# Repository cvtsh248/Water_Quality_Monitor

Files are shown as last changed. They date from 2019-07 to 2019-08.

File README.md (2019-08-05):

# Water Quality Monitor

This is an affordable, work-in-progress arduino based system that rates/monitors changes in water quality over a period of time. The system could potentially be used to monitor/rate the changes in tap water over time. When a significant change occurs, the system alerts the user. A change in water quality could indicate some form of contamination. 

The system currently monitors total dissolved solids (TDS) and turbidity using homemade sensors. More information is provided in the [wiki](https://github.com/cvtsh248/Water_Quality_Monitor/wiki). 

# Components Required
More information regarding the construction of the sensors and circuitry is in the [wiki](https://github.com/cvtsh248/Water_Quality_Monitor/wiki).
* Computer with functional USB ports.
* Arduino UNO 
* Resistors (10kΩ, 3.3kΩ, 100Ω, 20kΩ), note that you may need resistors of other values, more information is provided in the [wiki](https://github.com/cvtsh248/Water_Quality_Monitor/wiki)
* Wire
* Red LED (for the turbidity sensor)
* Light Dependent Resistor (for the turbidity sensor)
* Bottle Cap (For turbidity sensor, more infornamtion in the [wiki](https://github.com/cvtsh248/Water_Quality_Monitor/wiki))
* Plugpoint with two functional prongs (for the TDS sensor)

# Software Dependencies
* Processing IDE
  * processing.serial
  * controlP5
  * java.io.BufferedWriter
  * java.io.FileWriter
* Arduino IDE

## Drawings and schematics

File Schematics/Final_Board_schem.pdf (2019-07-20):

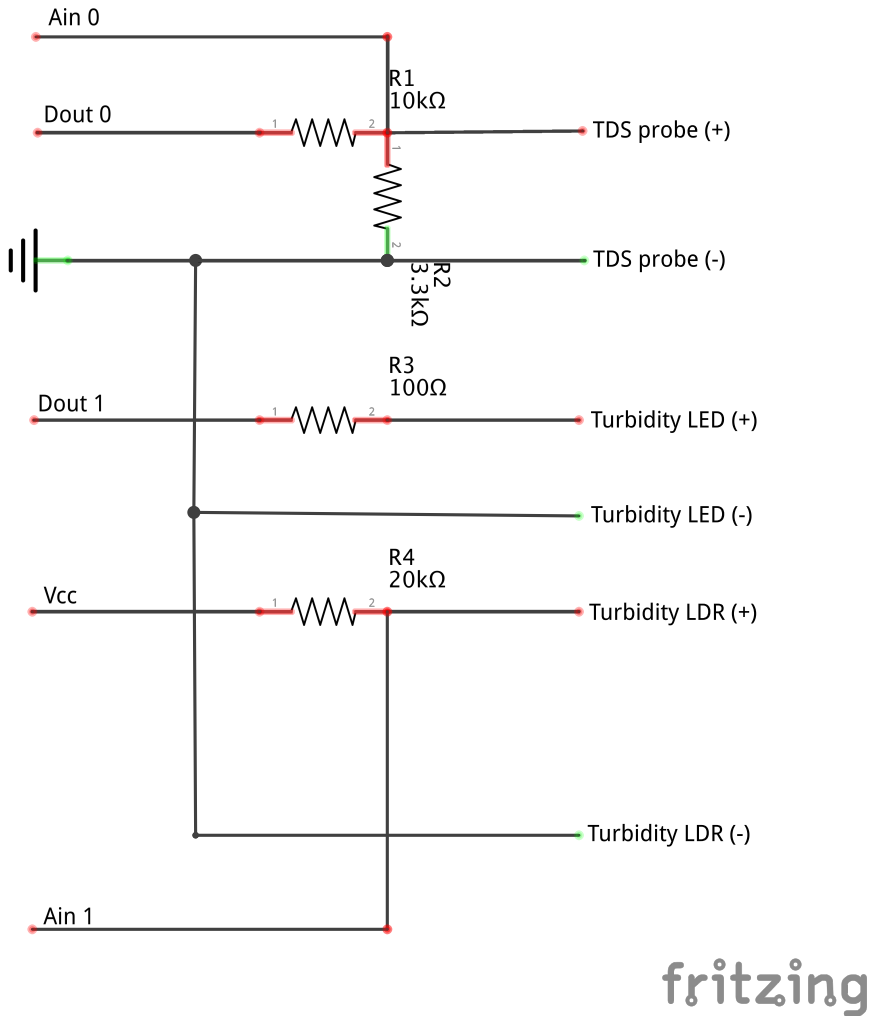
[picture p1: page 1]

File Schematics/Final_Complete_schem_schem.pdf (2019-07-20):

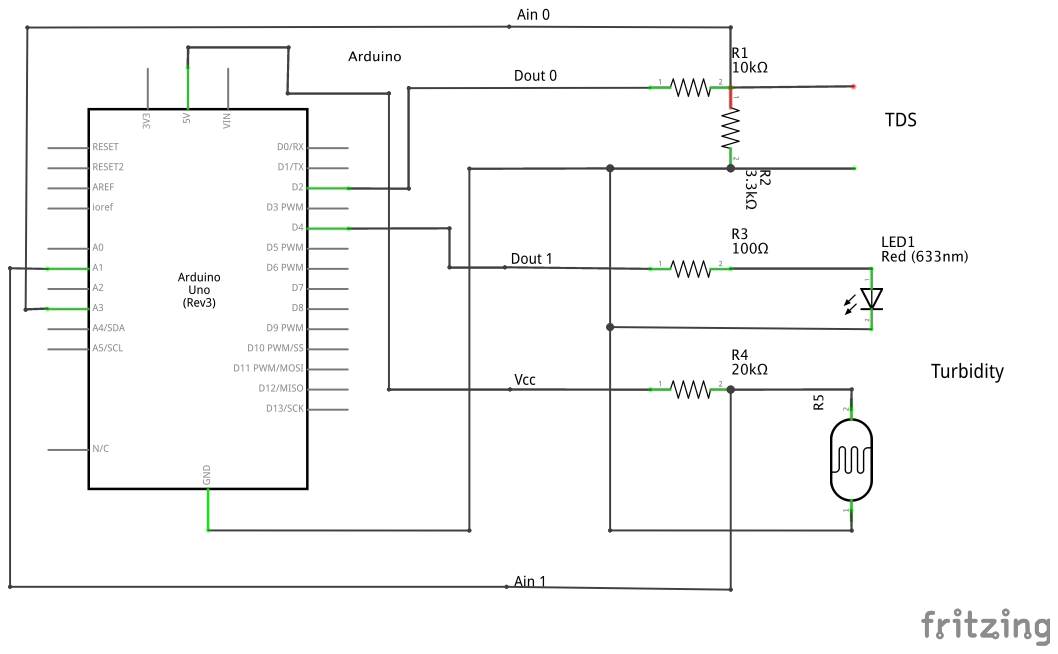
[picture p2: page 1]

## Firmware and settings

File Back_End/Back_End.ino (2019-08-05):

// Backend

/*
 * TO DO:
 * 1. Add in turbidity functionality [DONE]
 * 2. Calibrate sensor [DONE]
 */

void setup() {
  Serial.begin(9600);
  analogReference(INTERNAL);
  pinMode(2, OUTPUT);
  pinMode(4, OUTPUT);

}

//for tds
float volt = 0; 
float avg = 0;
char incoming; //see when to send what

//for turbidity
float val_light = 0;
float val_no_light = 0;
float val = 0;
float avgval = 0;

void loop() {
  avg = 0;
  if (Serial.available()>0){
    
    incoming = Serial.read();
    Serial.println(incoming);
    /*
     *  To prevent electrolysis,
     *  the program does not apply a constant voltage to the water, 
     *  but only when you ask the program to send you a reading.
     */
    if (incoming == 'd'){ //tds
      //reading data
      for (int i = 0; i <= 100; i++){
        digitalWrite(2, HIGH);
        volt = analogRead(A3);
        avg += volt; //an average is taken for the sake of accuracy, and denoising
      }
      digitalWrite(2, LOW);
      avg = avg/100;
      
      
    /*
     * A turbidity sensor measures the cloudiness of water. 
     * This can be achieved using a LDR and a LED. 
     * The less light that comes through from the LED to the LDR, the cloudier the water is. 
     * To cancel out background light, I am turning the LED on and off every 50 milliseconds. 
     * The reading of the LDR during the time that the LED is off 
     * can be subtracted from the reading of the LDR during the 
     * time that the LED is on, to get a final turbidity reading, 
     * free of background light. 
     * In theory this eliminates the need of something 
     * like a dark box for the system to be housed in. 
     */
      //reading data
      for (int n = 0; n <= 20; n++){
        digitalWrite(4, LOW); 
        val_no_light = analogRead(A1); //reading with no light
        delay(10); //1 ms delay
        digitalWrite(4, HIGH);
        val_light = analogRead(A1); //reading with light on
        delay(10); //1 ms delay
        val = val_light-val_no_light; //subtracting the two
        avgval += val;
      }
      digitalWrite(4, LOW); 
      avgval /= 20; //calculating average for the sake of accuracy/denoising
      
      Serial.print(avg); //average printed to serial
      Serial.print(',');
      Serial.println(avgval); //print to serial
      
      avgval = 0;
      avg = 0;
    }
  }
  Serial.flush();
}

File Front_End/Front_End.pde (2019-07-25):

//Front End

/*

This is the front end.
This works in unison with the back end.
Only edit lines that ask you to,
if you don't want to break anything.

*/

import controlP5.*;

import processing.serial.*;

import java.io.BufferedWriter;

import java.io.FileWriter;

Serial arduino;

ControlP5 cp5;

float std(float data[]) { //function to calculate standard deviation
  float avg = 0;
  float stdev = 0;
  float nans = 0; //count how many nan
  for (int i = 0; i < data.length; i++) { //calculating average
    if (Float.isNaN(data[i])==false){
      avg += data[i];
    }
    if (Float.isNaN(data[i])==true){
      nans+=1;
    }
  }
  avg /= (data.length-nans);
  for (int i = 0; i < (data.length-nans); i++) {
    if (Float.isNaN(data[i])==false){
      stdev += sq(data[i]-avg);
    }
    
  }
  stdev /= (data.length-nans); //calculating standard deviation
  stdev = sqrt(stdev);
  return (stdev);
}

boolean sigma(float data[], float val){ //evaluate standard deviation
  float stdev = std(data);
  float avg = 0;
  float nans = 0; //count how many nan
  float diff = 0;
  float sigmas = 0;
  for (int i = 0; i < data.length; i++) { //calculating average
    if (Float.isNaN(data[i])==false){
      avg += data[i];
    }
    if (Float.isNaN(data[i])==true){
      nans+=1;
    }
  }
  avg /= (data.length-nans);
  diff = val-avg;
  
  sigmas = diff/stdev;
  println(sigmas);
  if (abs(sigmas) > 3){
    return (true);
  }else{
    return (false);
  }
}


String buff[] = {""}; //reseting file
float Buff[] = {}; //for reseting lists
float tds[] = {}; //tds values
float turbidity[] = {}; //turbidty values
String val = null; //buffer for tds
String val_t = null; //buffer for turbidity
boolean range = false; //in acceptable range of standard deviation or not (tds)
boolean range_t = false; //same as range but for turbidity 
float s = 0; //variable containing standard deviation for tds
float s_t = 0; //standard deviation for turbidity
String [] lines; //open file for tds
String [] lines_t; //open file for turbidity

void setup() {
  size(400,400);
  
  arduino = new Serial (this, "/dev/ttyACM0", 9600); //initialising arduino serial connection
  arduino.bufferUntil( '\n' );
  
  lines = loadStrings("log_tds.txt"); //load save file for tds
  lines_t = loadStrings("log_turb.txt"); //load save file for turbidity
  
  //gui elements
  cp5 = new ControlP5(this);
  cp5.addButton("Data").setValue(0).setPosition(20,40).setSize(90,40);
  cp5.addButton("Save").setValue(0).setPosition(20,100).setSize(90,40);
  cp5.addButton("Reset").setValue(0).setPosition(20,160).setSize(90,40);
  
  for (int i = 0; i < lines.length; i++){
    tds = append(tds,float(lines[i]));
  }
  
  for (int i = 0; i < lines_t.length; i++){
    turbidity = append(turbidity,float(lines_t[i]));
  }
  
}


void draw() { //begin application
  //tds
  background(0); //refresh background
  text("Value of TDS:",160,45);
  if (tds.length > 0 && val != null){
    text(float(val),250,45); //display tds value, in calibration mode: taking value from tds buffer array
    //text(float(val)*m+c,250,45); <If you have calibration data (linear), uncomment this line and comment out line 119, replace m with gradient and c with constant and remove this text>
    //text(a*pow(float(val),exp)+c,250,45); <If you have calibration data (exponential), uncomment this line and comment out line 119, replace exp with the exponent and c with constant and remove this text>
    //text(a*pow(float(val),2)+b*(float(val))+c,250,45); <If you have calibration data (quadratic), uncomment this line and comment out line 119, replace a with the coefficient of x^2, b with the coefficient of x and c with constant and remove this text>
    
  }
  if (val != null){
    s = std(tds); //calculate standard deviation of the tds array
  }
  text("Standard Deviation:",160,70); //lines 82&83 are responsible for displaying standard deviation
  text(String.format("%.5f", s),290,70);

  text("Abnormal:",160,95); //check for abnormality (i.e. outside acceptable difference based on standard deviation)
  if (range == true){ //uses the boolean function within_range()... Look at bool within_range() for more info. 
    text("true",230,95);
  }
  if (range == false){
    text("false",230,95);
  }
  
  //turbidty
  text("Value of turbidity:",160,150);
  if (turbidity.length > 0 && val_t != null){
    text(float(val_t),280,150); //display tds value, in calibration mode: taking value from tds buffer array
    //text(float(val_t)*m+c,250,45); <If you have calibration data (linear), uncomment this line and comment out line 142, replace m with gradient and c with constant and remove this text>
    //text(a*pow(float(val_t),exp)+c,250,45); <If you have calibration data (exponential), uncomment this line and comment out line 142, replace exp with the exponent and c with constant and remove this text>
    //text(a*pow(float(val_t),2)+b*(float(val_t))+c,250,45); <If you have calibration data (quadratic), uncomment this line and comment out line 142, replace a with the coefficient of x^2, b with the coefficient of x and c with constant and remove this text>
  }
  if (val_t != null){
    s_t = std(turbidity); //calculate standard deviation of the tds array
  }
  text("Standard Deviation:",160,175); //lines 82&83 are responsible for displaying standard deviation
  text(String.format("%.5f", s_t),290,175);

  text("Abnormal:",160,200); //check for abnormality (i.e. outside acceptable difference based on standard deviation)
  if (range_t == true){ //uses the boolean function within_range()... Look at bool within_range() for more info. 
    text("true",230,200);
  }
  if (range_t == false){
    text("false",230,200);
  }
  
  
}

//buttons galore
public void Data() { //receive data button function
  
  arduino.write('d'); //send the char 'd' to the arduino
  delay(15);
  val = arduino.readStringUntil('\n'); //receive the response (spam this button at least 5 times to get fresh data)
  
  val_t = val.split(",")[1];
  val = val.split(",")[0];
  
  arduino.clear();//clear buffer
  
}
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

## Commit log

2019-06-20 TDS sensor code
2019-07-02 Communication between arduino and frontend fixed
2019-07-15 Improved communication between host computer and arduino
2019-07-20 Added schematics of project
    [Final_Board.fzz, Final_Complete_schem.fzz]
2019-07-21 Fixed serial communication, improved turbidity sensitivity
    [Back_End.ino]
2019-07-21 Fixed serial communication bug
    [Front_End.pde]
2019-07-22 Added "Support" for calibration
2019-07-22 bug spotted, saves data incorrectly
    [Front_End.pde]
2019-07-22 Tool to help with calibration
2019-07-24 Improved calibration support, removed redundant stuff
2019-08-05 Increased resolution, changed reference voltage
